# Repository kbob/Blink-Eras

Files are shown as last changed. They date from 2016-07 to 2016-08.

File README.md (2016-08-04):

# Eras of Blinking

Blinking an LED as it was done in the 1970s (555) and the 1990s (AVR).

I am using this project to learn KiCAD and SMT fabrication.  Also
learning to use pogo pins to flash a microcontroller.

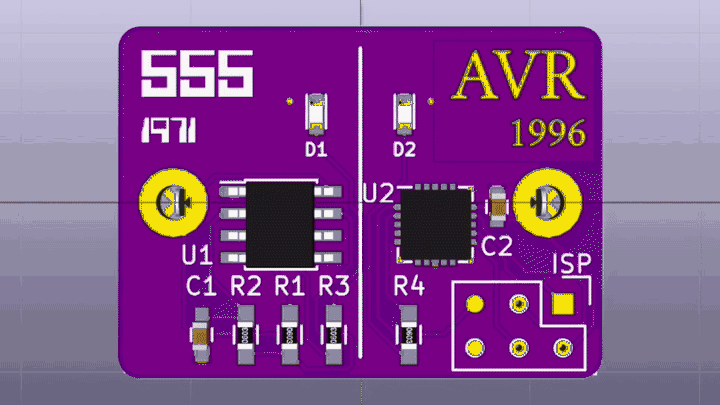
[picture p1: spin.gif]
KiCAD has a 3D viewer.


# The ISP Pogo Jig

I designed and built a jig to hold pogo pins against the board's ISP
headers to program the AVR.  In the end, I did not use the jig; it did not
press the pogo pins against the contacts hard enough to make a solid
connection.

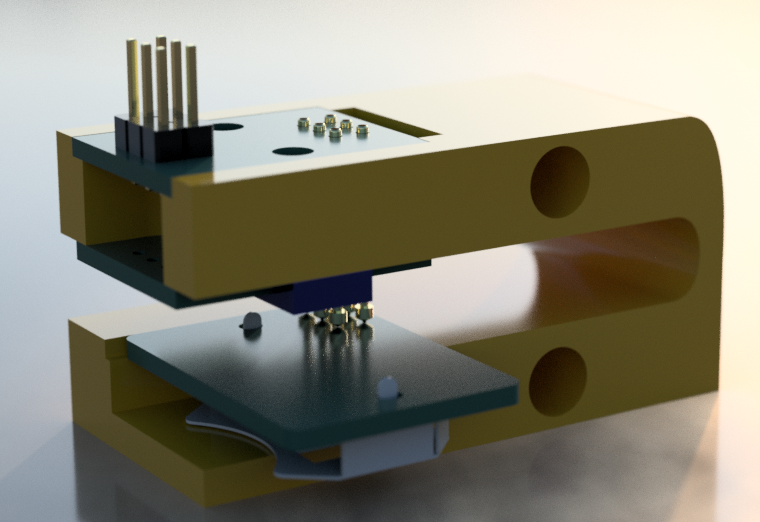
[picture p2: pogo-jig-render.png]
Pogo jig render


I found Nick Sayers'
[AVR ISP Pogo Adapter v0.5](https://oshpark.com/shared_projects/iyo8KOe5)
on OSH Park and ordered it.  I soldered the pogo pins to two boards 7
mm apart so the pins would be well aligned.

I use [ecad.io](https://ecad.io) to create STEP files representing the
boards' geometric shapes.  I imported the boards into Fusion 360,
modeled a pogo pin, and designed a jig around them.

The [Fusion 360 model is here](http://a360.co/2aq1vVH).  

If I did it again, I would do it very differently.  I think I would
flip the jig over so the board sits on top, with some kind of latch to
hold it in place.

# Differences between v1.0 and v1.1

  - Shrink through holes for battery clip.
  - Eliminate rectangle around "AVR" lettering.
  - Change "555" and "1971" lettering to get better separation.
  - Enlarge "CR2032" lettering.
  - Enlarge presidents' caricatures, just keep the faces.
  - Increment the silkscreen version number.

# Resources

[Getting to Blinky 4.0](https://www.youtube.com/playlist?list=PLy2022BX6Eso532xqrUxDT1u2p4VVsg-q)
Video tutorials for KiCAD 4.0

[Flashing LED Circuit](http://www.555-timer-circuits.com/flashing-led.html)
Simple 555 astable circuit.  Cribbed mercilessly.

[How to Build an AVR Blinking LED Circuit](http://www.learningaboutelectronics.com/Articles/AVR-blinking-LED-circuit.php)

[Programming an ATtiny w/ Arduino 1.6](http://highlowtech.org/?p=1695)

[LED Resistor Calculator](http://led.linear1.org/1led.wiz)

[3D KiCAD Parts tutorial](http://happyrobotlabs.com/posts/tutorials/tutorial-3d-kicad-parts-using-openscad-and-wings3d/)

[KiCAD graphics tutorial](http://blog.komar.be/making-pcb-artwork-in-kicad/)

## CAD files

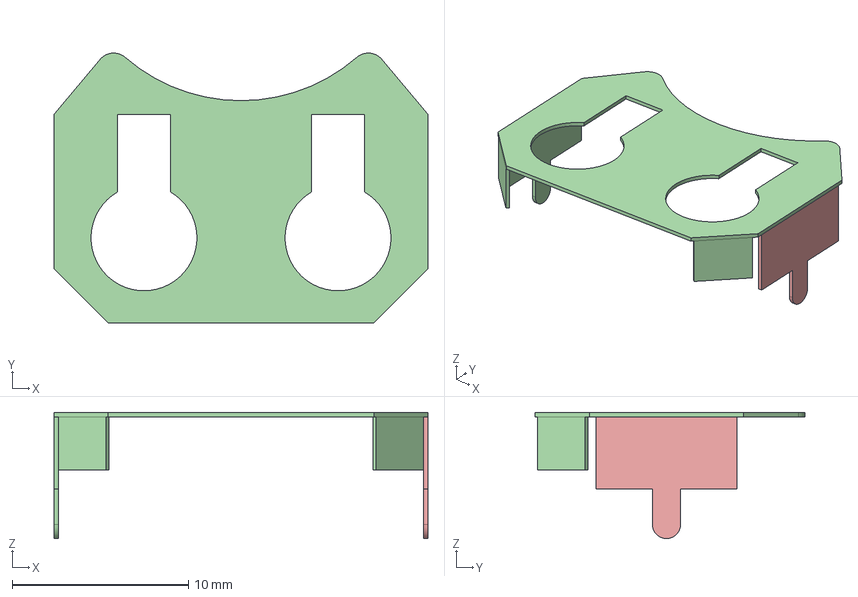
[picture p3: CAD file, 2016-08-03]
FreeCAD/BK-913.step
21.2 x 15.3 x 7.15 mm
Sketch
Sketch003
Sketch004
Sketch001
Sketch002

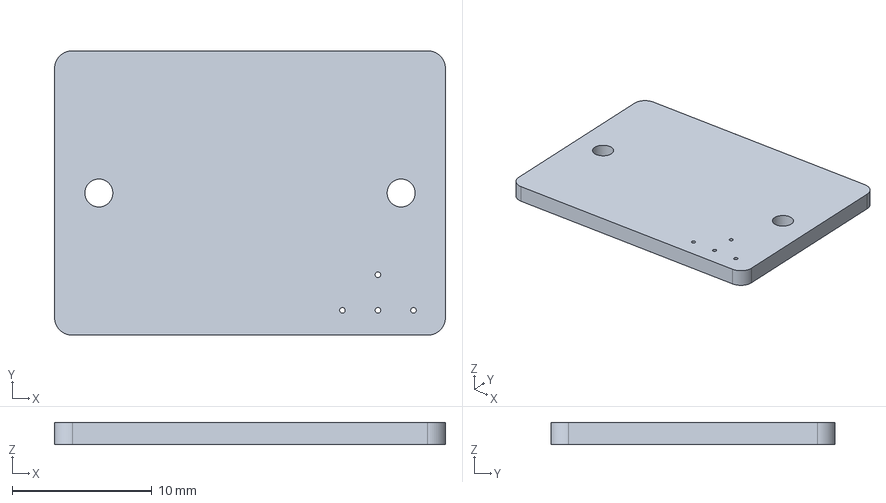
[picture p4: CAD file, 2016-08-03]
Pogo Jig/Blink Eras.STEP
27.9 x 20.3 x 1.60 mm

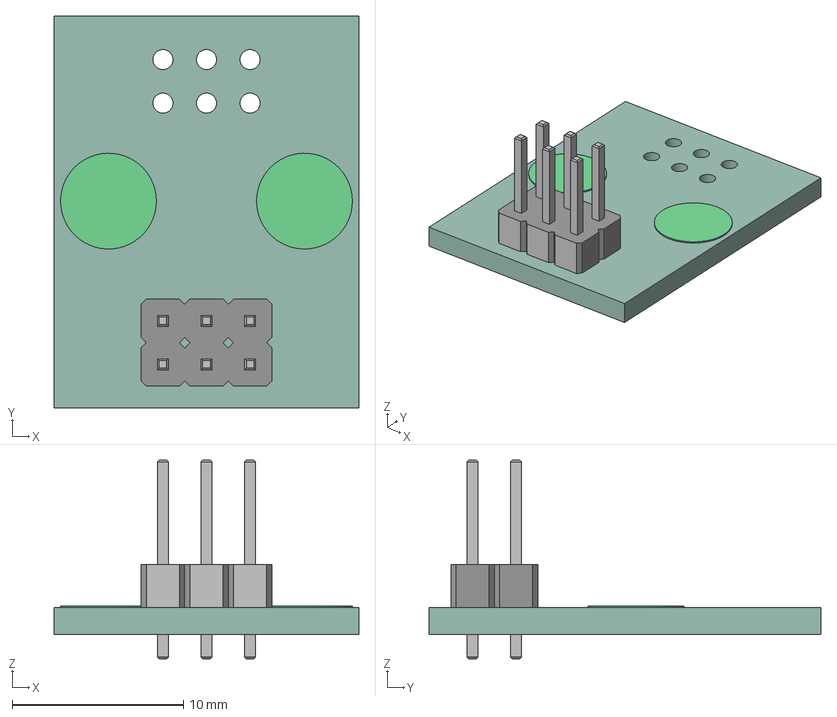
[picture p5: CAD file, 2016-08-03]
Pogo Jig/design.STEP
17.8 x 22.9 x 11.6 mm
PCB
AVR-ISP-6
KEEPOUT x 2

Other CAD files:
FreeCAD/BK-913.FCStd

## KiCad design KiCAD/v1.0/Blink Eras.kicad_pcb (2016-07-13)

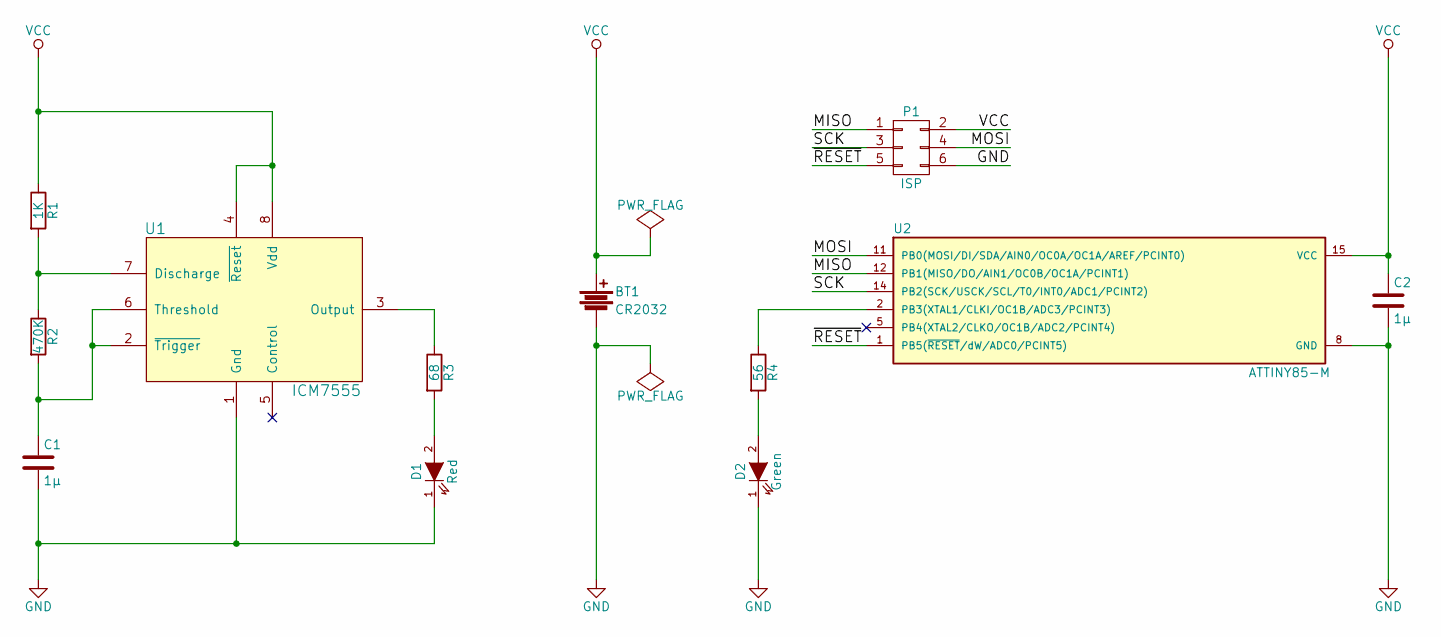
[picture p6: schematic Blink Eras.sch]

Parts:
BT1: CR2032; BK-913
C1, C2: 1µ; C_0603_HandSoldering
D1: Red; LED_0603
D2: Green; LED_0603
P1: ISP; ISP_Pogo_3-thru
R1: 1K; R_0603_HandSoldering
R2: 470K; R_0603_HandSoldering
R3: 68; R_0603_HandSoldering
R4: 56; R_0603_HandSoldering
U1: ICM7555; SOIC-8_3.9x4.9mm_Pitch1.27mm
U2: ATTINY85-M; QFN-20-1EP_4x4mm_Pitch0.5mm

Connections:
/MISO: P1.1, U2.12 (PB1(MISO/DO/AIN1/OC0B/OC1A/PCINT1))
/MOSI: P1.4, U2.11 (PB0(MOSI/DI/SDA/AIN0/OC0A/OC1A/AREF/PCI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)
/SCK: P1.3, U2.14 (PB2(SCK/USCK/SCL/T0/INT0/ADC1/PCINT2))
/~RESET~: P1.5, U2.1 (PB5(~RESET~/dW/ADC0/PCINT5))
GND: BT1.2, C1.2, C2.2, D1.1 (K), D2.1 (K), P1.6, U1.1 (Gnd), U2.8 (GND)
unnamed: C1.1, R2.2, U1.2 (~Trigger~), U1.6 (Threshold)
unnamed: D1.2 (A), R3.2
unnamed: D2.2 (A), R4.2
unnamed: R1.2, R2.1, U1.7 (Discharge)
unnamed: R3.1, U1.3 (Output)
unnamed: R4.1, U2.2 (PB3(XTAL1/CLKI/OC1B/ADC3/PCINT3))
VCC: BT1.1, C2.1, P1.2, R1.1, U1.4 (~Reset~), U1.8 (Vdd), U2.15 (VCC)

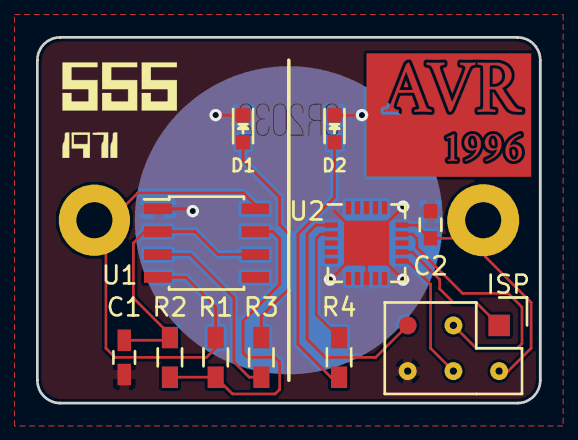
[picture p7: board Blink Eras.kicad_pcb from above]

Board: 2 copper layers, 27.9 x 20.3 mm, 12 parts (1 on the bottom side), 12 nets.

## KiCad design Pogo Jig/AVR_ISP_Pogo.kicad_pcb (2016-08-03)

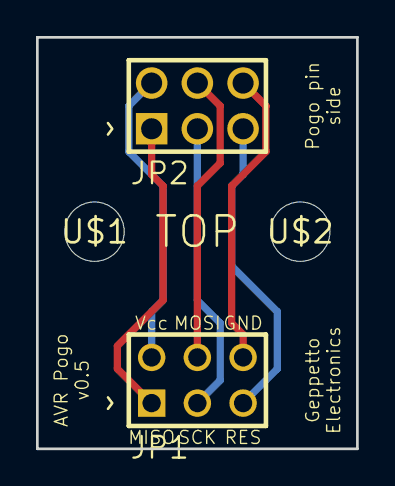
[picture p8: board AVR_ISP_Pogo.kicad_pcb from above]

Board: 2 copper layers, 17.8 x 22.9 mm, 4 parts (0 on the bottom side), 6 nets.

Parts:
JP1: AVR-ISP-6VERT; AVR-ISP-6
JP2: POGO-PIN-ISP46MIL; AVR-PPINS-46-6ISP
U$1, U$2: STAND-OFF

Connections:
unnamed: JP1.2, JP2.2
unnamed: JP1.4, JP2.4
unnamed: JP1.6, JP2.6
unnamed: JP1.1, JP2.1
unnamed: JP1.3, JP2.3
unnamed: JP1.5, JP2.5

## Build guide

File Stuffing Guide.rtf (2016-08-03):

U1 7555
U2 ATtiny85

R1 1K
R2 470K
R3 68
R4 56

C1 1µ
C2 1µ

D1 red
D2 green

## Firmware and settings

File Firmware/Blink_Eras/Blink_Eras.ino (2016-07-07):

ISR(TIMER1_OVF_vect)
{
  static int8_t inc = +1;
  static uint8_t brightness = 0;
  OCR1B = brightness;
  brightness += inc;
  if (brightness == 0 || brightness == 255)
    inc = -inc;
}

int main()
{
  TCCR1 = _BV(CS12);
  GTCCR = _BV(PWM1B) | _BV(COM1B0);
  TIMSK = _BV(TOIE1);
  DDRB = _BV(DDB3) | _BV(DDB4);
  MCUCR = _BV(SE);
  PRR = _BV(PRTIM0) | _BV(PRUSI) | _BV(PRADC);
  sei();

  while (1)
    __asm__ ( "sleep" );
}

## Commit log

2016-07-07 Initial commit. Schemmatic drawn but fails DRC.
    [Blink Eras.kicad_pcb, Blink Eras.sch]
2016-07-07 Schematic cleanup. Passes ERC.
    [Blink Eras.sch]
2016-07-07 Inverted power flag.
    [Blink Eras.sch]
2016-07-07 Added Arduino sketch for ATtiny.
2016-07-07 Footprints, values, refinement.
    [Blink Eras.sch]
2016-07-07 Moved Arduino and KiCAD into separate subdirectories.
    [Blink Eras.kicad_pcb, Blink Eras.sch]
2016-07-07 Added README and datasheets.
    [Blink Eras.sch]
2016-07-07 Created footprint for BK-913 battery holder.
    [Blink Eras.sch]
2016-07-08 Created 3D model of BK-913 coin cell retainer in FreeCAD.
    [BK-913.FCStd]
2016-07-09 PCB is routed.
    [Blink Eras.kicad_pcb]
2016-07-09 Battery holder was upside down. Corrected.
    [Blink Eras.kicad_pcb]
2016-07-10 Changed battery holder's 3D model reference to be project-relative.
    [Blink Eras.kicad_pcb]
2016-07-10 Hide passive component values.
    [Blink Eras.kicad_pcb]
2016-07-10 New layout makes the pogo pins fit.
    [Blink Eras.kicad_pcb, Blink Eras.sch]
2016-07-10 Routed pogo pins.
    [Blink Eras.kicad_pcb]
2016-07-10 Tied QFN20's ground pad to ground.
    [Blink Eras.kicad_pcb]
2016-07-10 Big round battery contact, six vias to ground plane.
    [Blink Eras.kicad_pcb]
2016-07-10 Moved ATtiny bypass cap.
    [Blink Eras.kicad_pcb, Blink Eras.sch]
2016-07-10 Cleaned up extraneous traces inside pads.
    [Blink Eras.kicad_pcb]
2016-07-10 GND zone did not quite cover the right edge of the board. Fixed.
    [Blink Eras.kicad_pcb]
2016-07-11 Artwork, first draft..
    [Blink Eras.kicad_pcb]
2016-07-13 README: added link for KiCAD graphics tutorial.
2016-07-13 Updated all artwork. Many layers.
    [Blink Eras.kicad_pcb]
2016-07-24 Removed unused footprints.
2016-08-03 Removed duplicate frame.
2016-08-03 All files for ISP pogo jig
    [AVR_ISP_Pogo.kicad_pcb, BK-913.step, Blink Eras.STEP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]
2016-08-03 Wrote a paragraph in README about redesigning the pogo pin jig.
2016-08-03 Archived off v1.0 of KiCAD files.
    [Blink Eras.kicad_pcb, Blink Eras.sch]
2016-08-04 Shrank battery through holes, re-did CR2032 lettering.
2016-08-04 v1.1 changes
    - Shrink through holes for battery clip.
    - Eliminate rectangle around "AVR" lettering.
    - Change "555" and "1971" lettering to get better separation.
    - Enlarge "CR2032" lettering.
    - Enlarge presidents' caricatures, just keep the faces.
    - Increment the silkscreen version number.
    [Blink Eras.kicad_pcb]
